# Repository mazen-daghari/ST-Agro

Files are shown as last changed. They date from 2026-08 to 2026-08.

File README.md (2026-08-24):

# ST-Agro: Wireless Data Acquisition and Control System






A low-power, STM32-based wireless data acquisition and control architecture designed for smart agriculture and industrial environmental monitoring. The system consists of a Master/Gateway Node connected to a PC via USB and multiple Sender (Sensor) Nodes deployed in the field. 

System capabilities include integrated SWD firmware deployment, live sensor telemetry (temperature, humidity, multi-gas detection), AI-driven threat assessment (fire/water hazard detection), GPS node mapping, real-time analytics charts, and remote actuator relay matrix control with emergency stop (E-STOP) functionality.

---

## Demonstration & Promotional Videos

* **Promotional Video:** ST-Agro Promotional Video (https://youtu.be/v6s37rHDwMU)
  
---

* **Dashboard Demonstration:** ST-Agro Dashboard Demo (https://youtu.be/QQxuJRQUxHk)

*Click the thumbnails above to view the videos on YouTube.*

---

## System Architecture

System Architecture
---

## Software & Hardware Visual Overview

The system relies on a unified desktop application built in Python using `customtkinter` for modern UI components, `matplotlib` for real-time analytics, `sqlite3` for local persistent storage, and `tkintermapview` for node mapping. The application acts as a dual-purpose software hub:

1. **Direct SWD Hardware Flashing:** Communicates directly with `STM32_Programmer_CLI.exe` to flash compiled binaries (`.elf`) to Master Node (Slot A) and Sender Nodes (Slot B) at base address `0x08000000` over SWD/JTAG interfaces.
2. **LoRa Gateway Supervision & Actuator Control:** Connects to the Master Node over Serial UART to parse incoming sensor telemetry, render live per-node metrics, display active GPS node positions, log background telemetry to SQLite (`node_telemetry.db`), and send remote 4-channel relay control commands or Emergency Stop (`E-STOP`) overrides.
### Application Software Interface

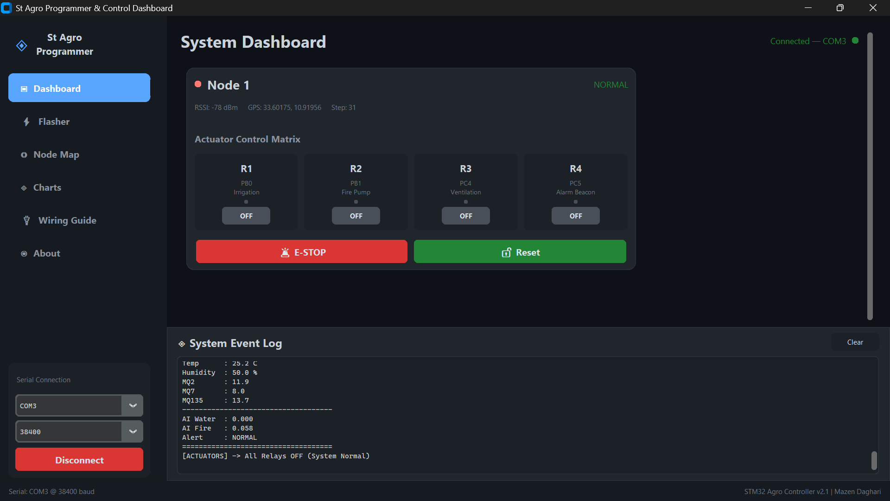
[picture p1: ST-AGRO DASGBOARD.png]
Dashboard View

*Figure 1: ST-Agro Control Dashboard showcasing live telemetry metrics, hazard risk calculations, real-time node statuses, relay controls, and global emergency stop features.*

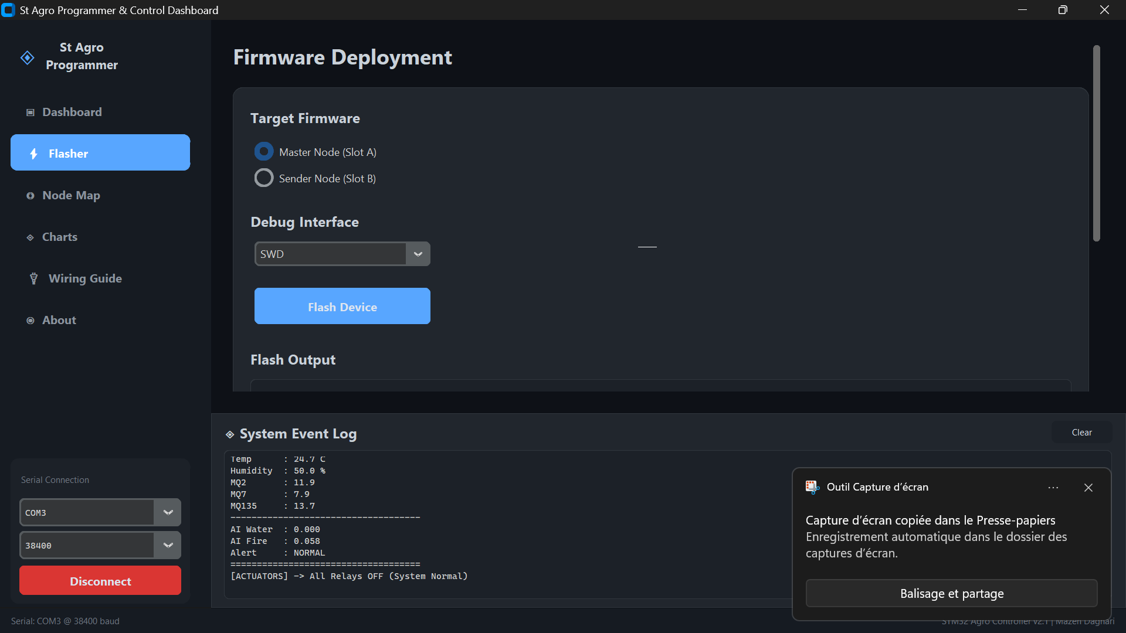
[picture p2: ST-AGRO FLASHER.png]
Flasher View

*Figure 2: SWD Flasher Interface used to flash Master (Slot A) and Sender (Slot B) firmware directly from the desktop application.*

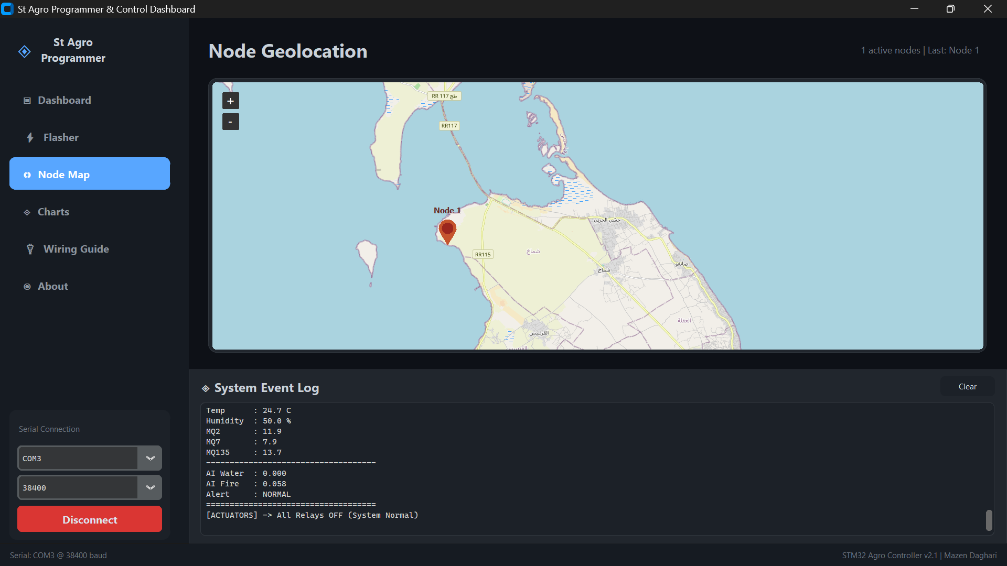
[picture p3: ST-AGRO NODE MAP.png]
Node Map View

*Figure 3: Integrated OpenStreetMap view displaying active field node locations based on live transmitted GPS spatial data.*

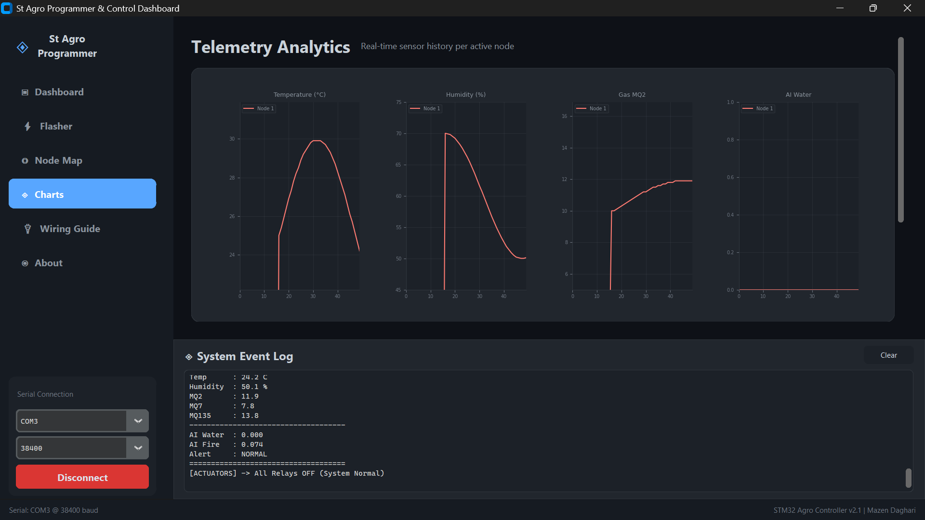
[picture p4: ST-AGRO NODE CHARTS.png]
Analytics Charts View

*Figure 4: Historical and real-time database aggregated analytics visualizing sensor trends and telemetry metrics per node.*

---

### Hardware PCB Layouts
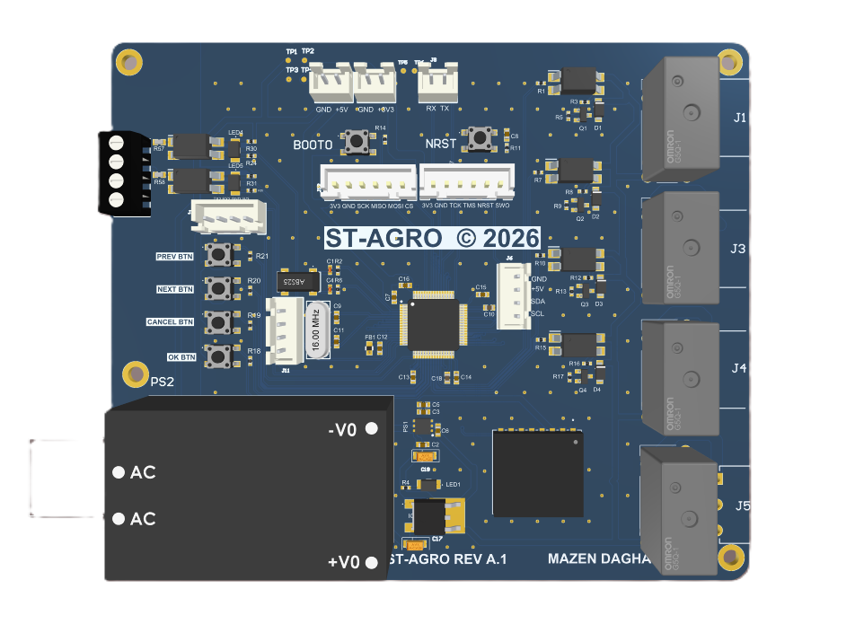
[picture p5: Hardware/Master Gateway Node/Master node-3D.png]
Master Node PCB 3D
.
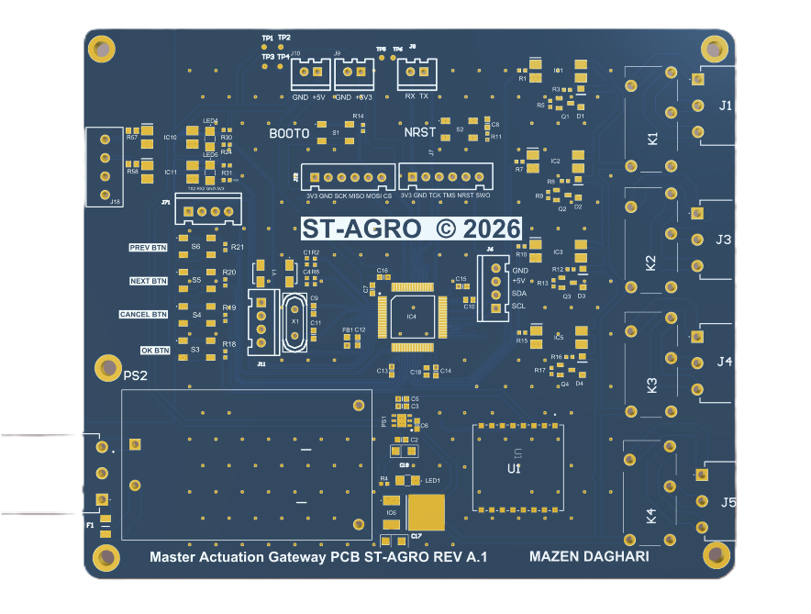
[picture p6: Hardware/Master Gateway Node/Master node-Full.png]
Master Node PCB


*Figure 5: Master/Gateway Node PCB featuring the STM32 microcontroller, USB communication interface, and SWD programming header.*

Sender Node PCB
Sender Node PCB

*Figure 6: Sender (Sensor) Node PCB integrating low-power STM32 architecture, sensor array interfaces, wireless transmitter, and power management circuits.*

---

## Core System Features

* **Integrated SWD Flasher Interface:** Deploy `Master Node (Slot A)` and `Sender Node (Slot B)` firmware binaries directly from the control desktop GUI without requiring external programming tools.
* **Low-Power Deep Sleep Cycle:** Sender nodes perform data collection, transmit packets to the Gateway, and immediately enter a 10-minute ultra-low-power deep sleep state to optimize battery consumption.
* **Multi-Sensor Telemetry Acquisition:**
  * Environmental Data: Temperature and Relative Humidity
  * Gas Array Monitoring: MQ2, MQ7, and MQ135 sensor payload values
* **Threat Intelligence Processing:** Real-time threat calculation providing automated risk scores for Fire Hazard and Water Quality alerts.
* **Actuator Control Matrix:** Remote execution and control of a 4-channel relay array (`R1: Irrigation`, `R2: Fire Pump`, `R3: Ventilation`, `R4: Alarm Buzzer`).
* **Emergency Stop (E-STOP):** Single-click software override that initiates an immediate hardware reset and emergency shutdown state across active nodes.
* **Node Geolocation Tracking:** Integrated OpenStreetMap spatial tracking displaying live GPS locations of active field nodes.
* **Database Aggregated Analytics:** Comprehensive historical and per-node real-time graphical metrics.

---

## Getting Started

### Hardware Requirements

1. Master/Gateway Node PCB (STM32-based controller)
2. Sender Node PCB(s) (STM32-based sensor nodes)
3. ST-LINK V2 / SWD Debugger
4. USB Cable (A-to-Micro or Type-C based on hardware design)
5. Sensor payload array (DHT/SHT series, MQ gas sensors, GPS module)
6. 4-Channel Relay Control Module

---

## Setup and Flashing Instructions

### Step 1: Flash the Master (Gateway) Node

1. Connect the ST-LINK programmer via the SWD header to the Master Node PCB.
2. Launch the **St Agro Programmer & Control Dashboard**.
3. Navigate to the **Flasher** tab on the left panel.
4. Under **Target Firmware**, select **Master Node (Slot A)**.
5. Set the debug interface to **SWD**.
6. Press and hold the hardware **RESET** button on the Master PCB for approximately 3 seconds, then click **Flash Device**.
7. Monitor the **System Event Log** until the process completes with the message `=== FLASH SUCCESSFUL ===`.

### Step 2: Flash the Sender Node(s)

1. Connect the ST-LINK programmer to the target Sender Node PCB.
2. In the **Flasher** tab, select **Sender Node (Slot B)**.
3. Hold the hardware **RESET** button on the Sender PCB for approximately 3 seconds, then click **Flash Device**.
4. Disconnect the debugging interface upon completion.
5. Repeat this sequence for each additional Sender Node within the network topology.

```text
Connect Programmer ──> Select Firmware Slot ──> Hold RESET (3s) ──> Click "Flash Device" ──> Verify Log Output
```

---

## System Operation and Communications

### Gateway Connection

1. Connect the programmed Master Node to the host computer using a USB cable.
2. In the desktop application under **Serial Connection**, click the refresh icon adjacent to the COM port menu.
3. Select the appropriate Master Node port (e.g., `COM3`) and set the baud rate to **38400**.
4. Click **Connect**. The status indicator in the upper right corner will confirm connection status (`Connected - COM3`).

### Node Deployment

1. Apply power to the Sender Node(s).
2. The Sender Node automatically collects sensor metrics and transmits telemetry packets to the Gateway Node.
3. Following each confirmed transmission, the node enters a **10-minute deep sleep cycle** prior to initiating the subsequent measurement cycle.

---

## Application Interface Overview

| Interface Section | Primary Function |
| :--- | :--- |
| **Dashboard** | Monitors active node state, hazard alerts (`FIRE_HAZARD`), live telemetry logs, relay matrix switching, and global **E-STOP** triggers. |
| **Flasher** | In-app firmware deployment interface for Master and Sender binaries via SWD. |
| **Node Map** | Geographical layout visualizing GPS coordinate data transmitted by deployed nodes. |
| **Charts & Global** | Graphical breakdown of historical database records and active per-node metric channels. |

---

## Troubleshooting Guide

* **COM Port Not Detected:** Verify FTDI/UART device driver installation and physical cable connection. Click the refresh control in the Serial Connection settings.
* **Firmware Flashing Failure:** Inspect SWD pin connections (`SWCLK`, `SWDIO`, `GND`, `3V3`). Ensure the physical **RESET** button is held for 3 seconds prior to clicking **Flash Device**.
* **Missing Telemetry Data:** Confirm the Sender node is powered and not currently operating within its 10-minute deep sleep phase. Press the physical RESET button on the Sender node to initiate an immediate transmission.

---
## Core System Features

* **Integrated SWD Flasher Interface:** Direct desktop firmware deployment via `STM32CubeProgrammer` CLI supporting SWD/JTAG modes for Master (`Slot A`) and Sender (`Slot B`) binaries targeting flash address `0x08000000`.
* **Low-Power Deep Sleep Cycle:** Sender nodes collect data, transmit packets to the Gateway, and immediately enter an ultra-low-power 10-minute deep sleep state to conserve battery.
* **Multi-Sensor Telemetry Acquisition:** 
  * Environmental Data: Temperature and Relative Humidity
  * Gas Array & Air Quality Monitoring: MQ2, MQ7, and MQ135 sensor payload values
* **AI-Driven Threat Intelligence:** Automated risk calculation for Fire Hazard (`AI Fire`) and Water Quality (`AI Water`) detection.
* **Actuator Control Matrix:** Remotely toggle a 4-channel relay matrix (`R1: Irrigation`, `R2: Fire Pump`, `R3: Ventilation`, `R4: Alarm Beacon`) on individual field nodes over LoRa.
* **Emergency Stop (E-STOP) Override:** Single-click software override per node that locks controls, turns off active relays, and broadcasts an emergency shutdown command (`NODE:<ID>:EMERGENCY_STOP`).
* **Node Geolocation Tracking:** Embedded OpenStreetMap module (`tkintermapview`) displaying real-time field positions based on live transmitted GPS coordinates.
* **SQLite Telemetry Logging & Analytics:** Automatic local database persistence (`node_telemetry.db`) with real-time per-node streaming charts and aggregated global network averages.
* **Hardware Interfacing Guide:** Built-in pinout reference tables for SWD (PA13/PA14), 20-pin JTAG, and ST-LINK/V2 dongles.
---
## Getting Started

### Hardware Requirements

1. Master/Gateway Node PCB (STM32-based controller)
2. Sender Node PCB(s) (STM32-based sensor nodes)
3. ST-LINK V2 / SWD Debugger
4. USB Cable (A-to-Micro or Type-C based on hardware design)
5. Sensor payload array (DHT/SHT series, MQ gas sensors, GPS module)
6. 4-Channel Relay Control Module

### Software Requirements
* Install and run St Agro Programmer V2.32
---
## Copyright and License

This software and hardware implementation is released under the **MIT License**.

```text
MIT License

Copyright (c) 2026 Mazen Daghari

Permission is hereby granted, free of charge, to any person obtaining a copy
of this software and associated documentation files (the "Software"), to deal
in the Software without restriction, including without limitation the rights
to use, copy, modify, merge, publish, distribute, sublicense, and/or sell
copies of the Software, and to permit persons to whom the Software is
furnished to do so, subject to the following conditions:

The above copyright notice and this permission notice shall be included in all
copies or substantial portions of the Software.

THE SOFTWARE IS PROVIDED "AS IS", WITHOUT WARRANTY OF ANY KIND, EXPRESS OR
IMPLIED, INCLUDING BUT NOT LIMITED TO THE WARRANTIES OF MERCHANTABILITY,
FITNESS FOR A PARTICULAR PURPOSE AND NONINFRINGEMENT. IN NO EVENT SHALL THE
AUTHORS OR COPYRIGHT HOLDERS BE LIABLE FOR ANY CLAIM, DAMAGES OR OTHER
LIABILITY, WHETHER IN AN ACTION OF CONTRACT, TORT OR OTHERWISE, ARISING FROM,
OUT OF OR IN CONNECTION WITH THE SOFTWARE OR THE USE OR OTHER DEALINGS IN THE
SOFTWARE.
```

### Citation Notice

For academic, scientific, or technical research projects utilizing this design, please cite the developer as follows:

* **Author:** Electronic & Communication System Engineer **Mazen Daghari**
* **Project:** ST-Agro Wireless Acquisition System & Control Dashboard
* **Demonstration Reference:** https://youtu.be/QQxuJRQUxHk
 ### Paper & Citation
If you find this work useful in your research, please cite our paper:

> M. Daghari, "ST-Agro: Low-Power Wireless Data Acquisition System," *IEEE...*
> **Preprint / Paper:** [Link]

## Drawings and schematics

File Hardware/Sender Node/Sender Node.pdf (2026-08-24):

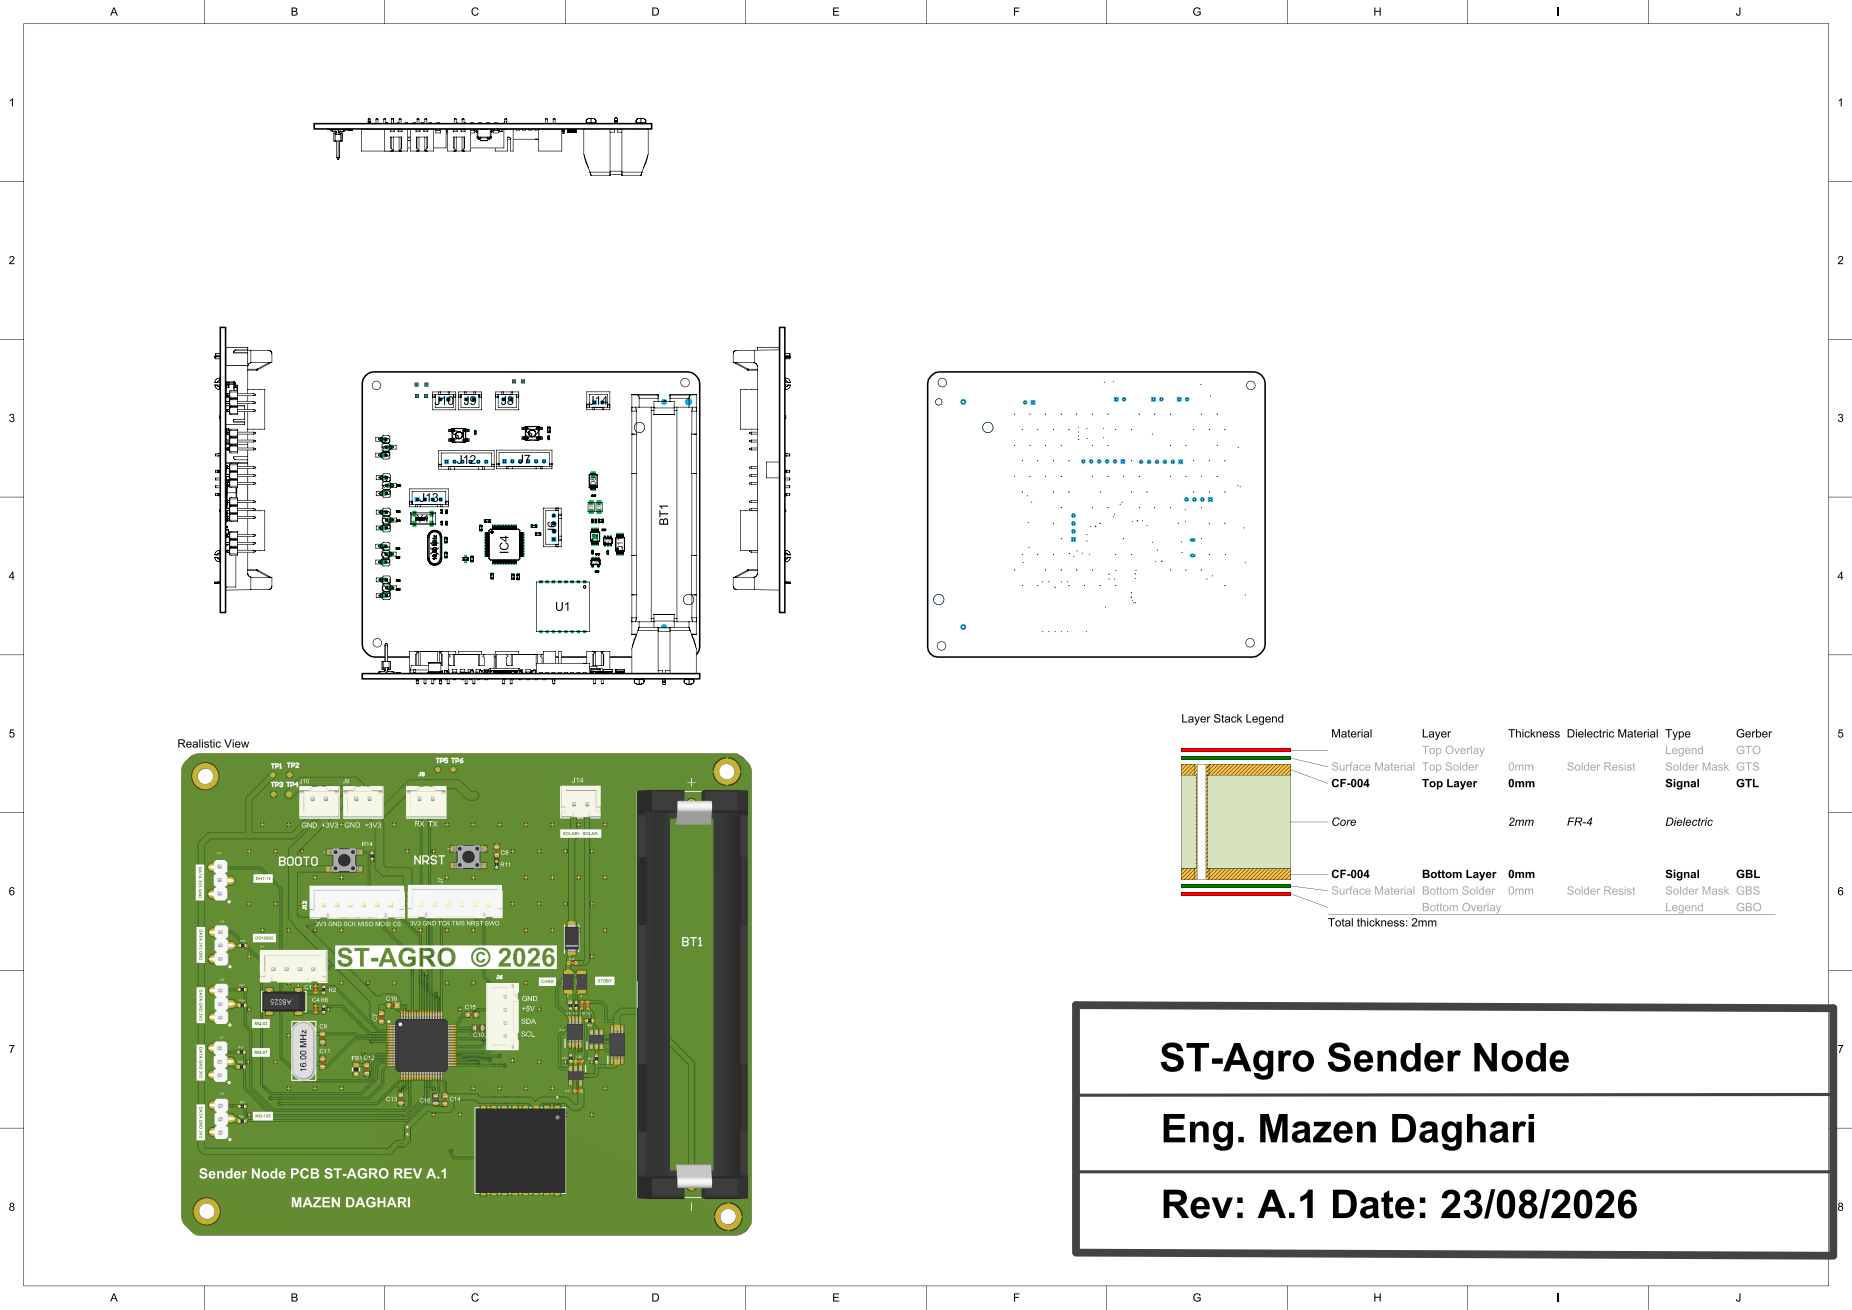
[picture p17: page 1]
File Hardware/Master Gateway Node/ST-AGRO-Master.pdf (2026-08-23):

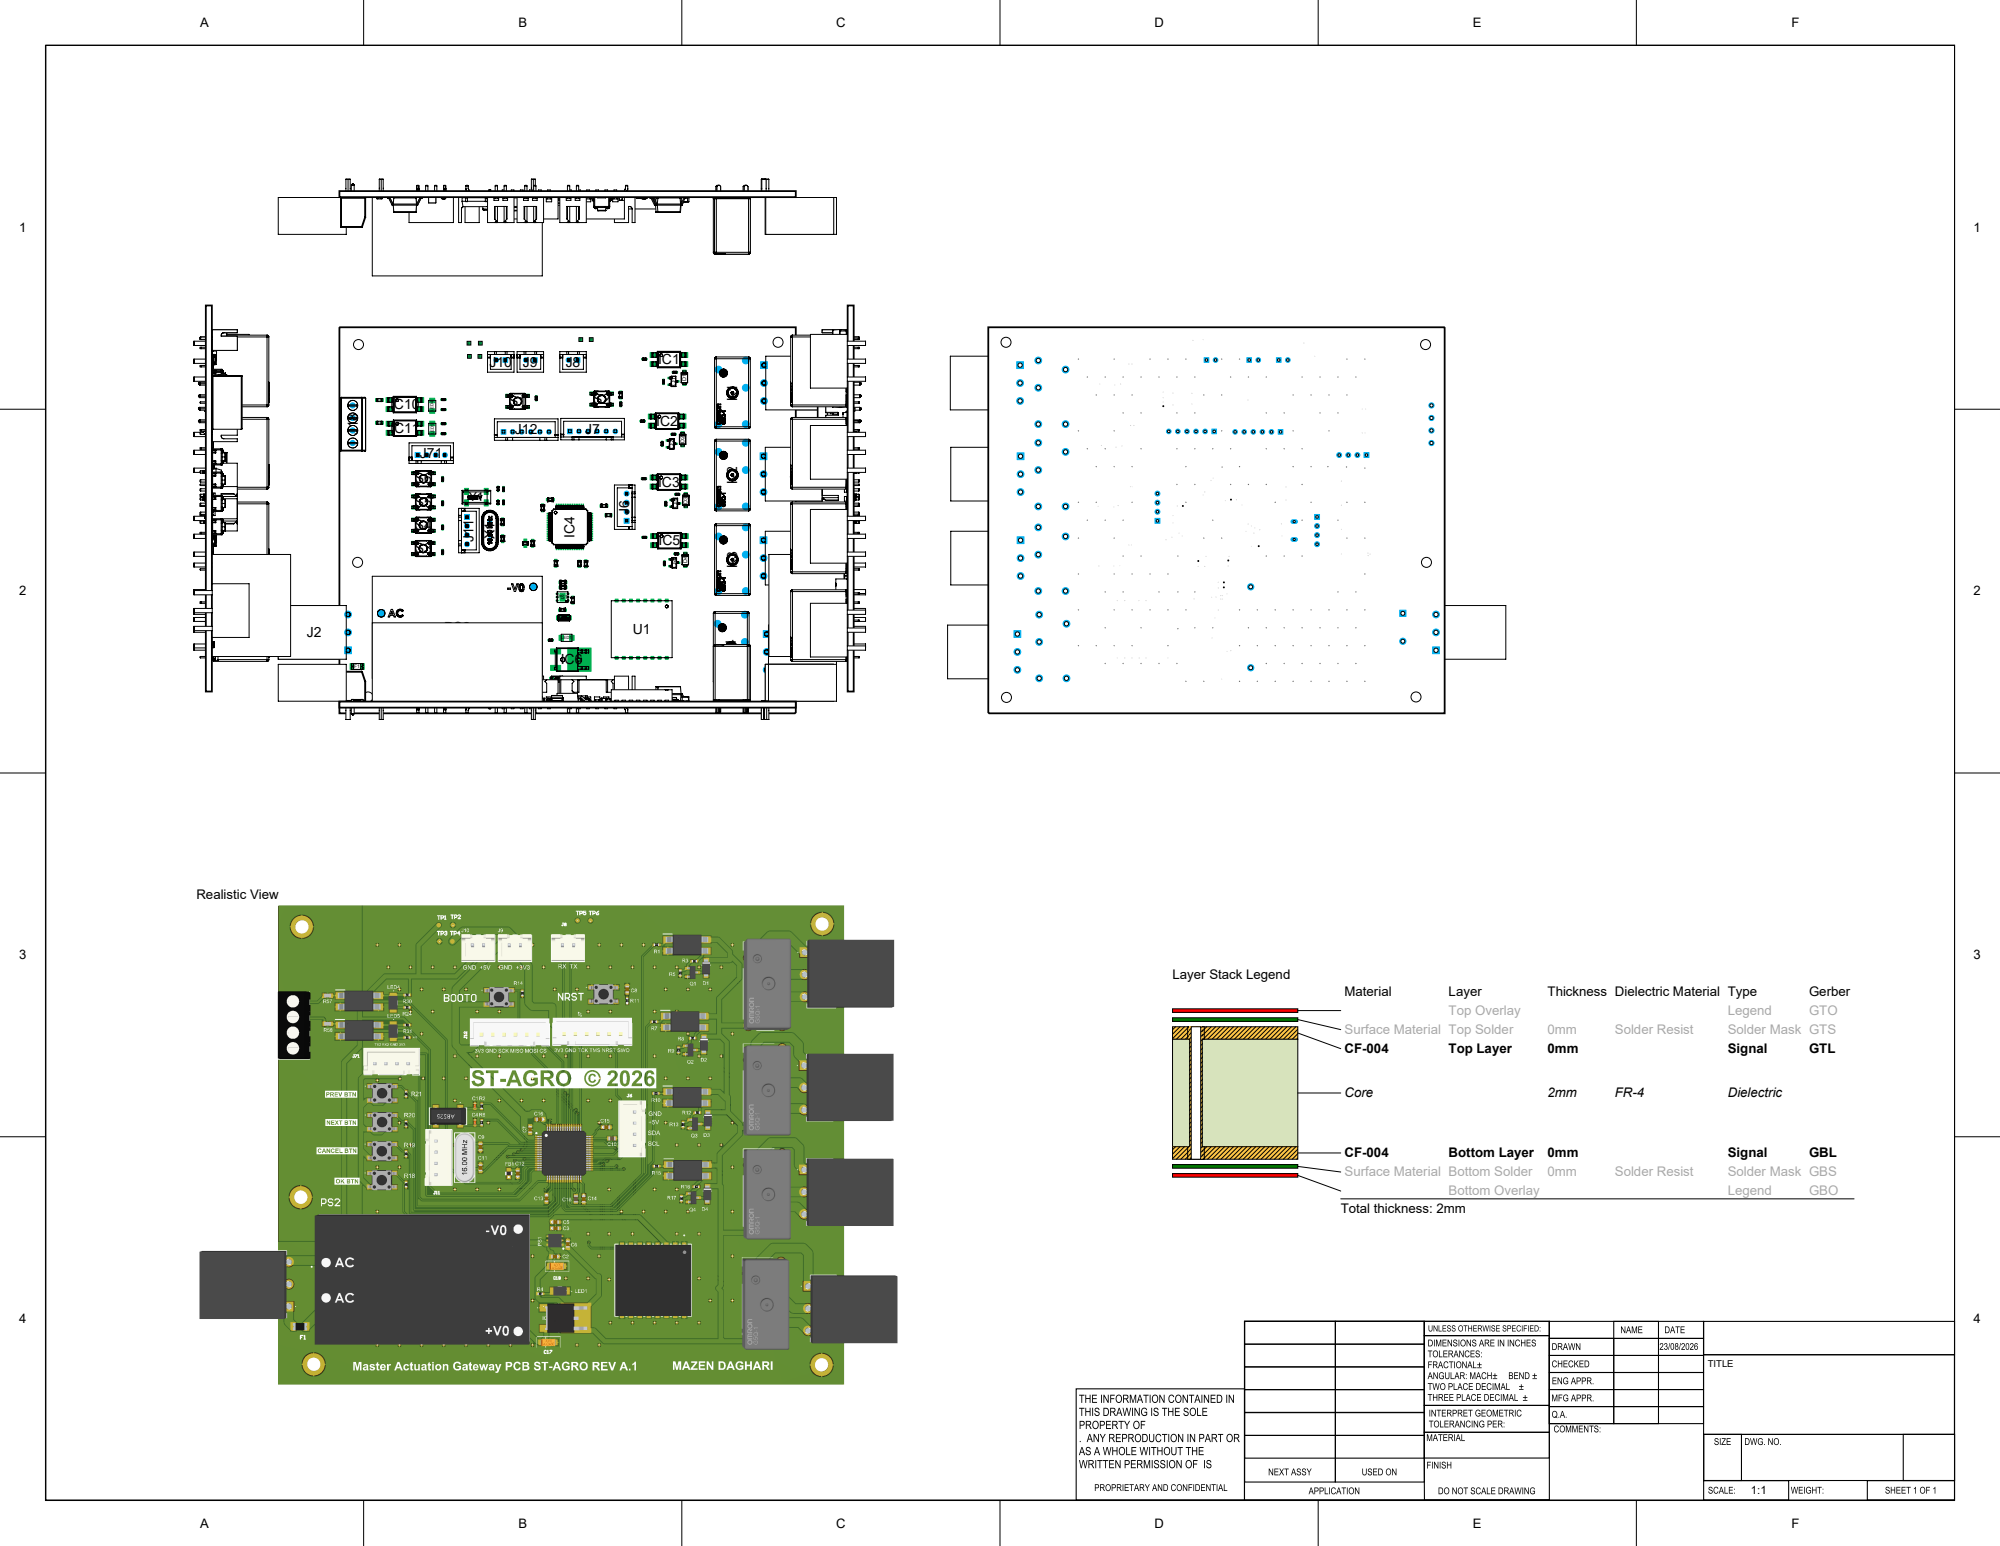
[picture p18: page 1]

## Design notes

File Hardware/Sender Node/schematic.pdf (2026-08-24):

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
Title

Size | Number | Revision
A2
Date: | 8/23/2026 | Sheet of
File: | C:\Users\..\ST-AGRO sender.SchDoc | Drawn By:

R2
0

R6
0

C1

4.3pF

C4

4.3pF

PC15

PC14

PC15

PC14

# Clock configuration

TMS SWO | TCK
NRST | UART⁵_RX UART⁵_TX

RA-02 DIO-0

SWO

NRST

TMS

TCK

3V3 | R14
10K | BOOT⁰

BOOT0

3V3

I2C_SDA

I2C_SCL

R11
10K

NRST

3V3

C8
100nF

# Power configuration

# Boot configuration

# I/O configuration

C9

22pF

C11

22pF

BOOT BTN | Reset BTN

3V3

3V3

3V3

3V3

3V3

C13
100nF

3V3

C14
100nF

C15
100nF

C16
100nF

C12
100nF

AVDD

AVDD

C7
1uF

3V3

Vbat

UART5_RX

UART5_TX

Xtal_in

Xtal_out

VBAT 1
PC13 2
PC14-OSC32_IN 3
PC15-OSC32_OUT 4
PF0-OSC_IN 5
PF1-OSC_OUT 6
NRST 7
PC0 8
PC1 9
PC2 10
PC3 11
VSSA 12
VDDA 13
PA0 14
PA1 15
PA2 16 | PA³ 17 VSS_1 18 VDD_1 19 PA⁴ 20 PA⁵ 21 PA⁶ 22 PA⁷ 23 PC⁴ 24 PC⁵ 25 PB⁰ 26 PB¹ 27 PB² 28 PB¹⁰ 29 PB¹¹ 30 VSS_2 31 VDD_2 32
VDD_3 | 48
VSS_3 | 47
PA13 | 46
PA12 | 45
PA11 | 44
PA10 | 43
PA9 | 42
PA8 | 41
PC9 | 40
PC8 | 39
PC7 | 38
PC6 | 37
PB15 | 36
PB14 | 35
PB13 | 34
PB12 | 33 VDD_4 64 VSS_4 63 PB⁹ ⁶² PB⁸ ⁶¹ BOOT⁰ ⁶⁰ PB⁷ ⁵⁹ PB⁶ ⁵⁸ PB⁵ ⁵⁷ PB⁴ ⁵⁶ PB³ ⁵⁵ PD² ⁵⁴ PC¹² ⁵³ PC¹¹ ⁵² PC¹⁰ ⁵¹ PA¹⁵ ⁵⁰ PA¹⁴ ⁴⁹ | IC4
STM32F303RET6

1

1
2

2

FB1

742792651 ¹ ² XTL_8MHz
X1
CRYSTAL_1 1 | GND_1 | 2
GND_2 | 3 CRYSTAL_2 4

Y1

ABS25-32-768KHZ-T

4

3

2

1

S2 ⁴

3

2

1

S1

I2C_SDA

I2C_SCL

3V3

3V3 | 1 2 | C18
| | GRM188R60J225KE19D

2 1

C10

GRM188R60J225KE19D SPI3_CS SPI3_MOSI | SPI3_MISO SPI3_SCK

SPI3_MOSI
SPI3_CS

SPI3_SCK
SPI3_MISO
3V3 | 3V3 | 3V3

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
UART5_RX | UART5_TX
TP5 | TP6

3.3V 3
MISO 13
MOSI 14
NSS 15
RESET 4
SCK 12

GND 1
GND 2
GND 9
GND 16
DIO0 | 5
DIO1 | 6
DIO2 | 7
DIO3 | 8
DIO4 | 10
DIO5 | 11

U1

RA-02

3V3 RA⁻⁰² RESET

RA-02 NSS

RA-02 SCK

RA-02 MISO

RA-02 MOSI

RA-02 NSS

RA-02 SCK

RA-02 MISO
RA-02 MOSI

RA-02 DIO-0

RA-02 RESET

# Sensors

# SX1278 - Ra-02 Communication Module

# Arm Cortex M4 STM32 f303RE

TEMP | 1
PROG | 2 GND

3

VCC 4
EP 9 CE 8

_CHRG 7
STDBY 6

BAT 5

IC23

TP4056-EMSOP8

D12_1 1
S1_1 2
S1_2 3
G1 4
D12_2 | 8
S2_2 | 7
S2_1 | 6
G2 | 5

Q11

FS8205A

OD 1
CS 2
OC 3
GND | 6
VCC | 5
TD | 4

IC21

DW01A-G | P N
BT1
1043
R42
15K
R41

1.5K ¹ ² LED7 1 2 LED6

C33
100nF

R43
4.7K

VIN 1
GND 2
SHUTDOWN 3
NC/ADJ | 4
VOUT | 5

IC20

AP2127K-3.0TRG1

R44
1.2K

C34
100nF

R45
100
C35
10uF 1
2
J14

+V SolarP

-V SolarP

+OUT

-OUT

C36
1uF

C37
10uF

3V3

2 1

D8

B140-E3_61T

R47
10K R48 18K

GND

MQ-02
R46
4.7K

3V3

DS18B20-Data PIN

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
J203V3 GND

R49
10K R50 18K

GND

MQ-07

1

2

3

J213V3 GND

R51
10K R52 18K

GND

MQ-135

1

2

3

J22 1 | 3V3 GND

2

3

J18
GND

3V3

DHT-11

3V3

3V3

DHT-11
DS18B20-Data PIN | MQ⁻⁰² | MQ⁻⁰⁷ MQ⁻¹³⁵
UART2_TX | UART²_RX

UART2_RX

UART2_TX 1
2
3
4
J13 | 3V3

* Sensors use **analog pins only**; digital pins must not be connected. The **DS18B20** sensor is used to ensure high-precision temperature measurement in harsh environments.

## SOLAR ENERGY HARVESTING & BATTERY MANAGEMENT SUBSYSTEM (SENDER NODE)

## 1. SOLAR PANEL INPUT SPECIFICATIONS:

- Rated Output: 5.5V / 290mA Photovoltaic (PV) Cell.
- Input Blocking Diode: MBR0540 (Schottky) to prevent reverse battery discharge.
- Transient Protection: SMAJ6.0A TVS diode placed across VIN to GND.

## 2. CHARGER IC PROGRAMMING (MCP73831 / EQUIVALENT):

- R_PROG Value: 3.9kΩ to 4.7kΩ (1%, 0402).

## - Fast-Charge Current Setting: ~220mA - 256mA (Matched to panel capability

to prevent solar voltage collapse and continuous UVLO oscillation).

## 3. DECOUPLING & FILTERING CAPACITORS:

- C_IN (VIN to GND): 4.7µF X5R/X7R Ceramic (0805) placed at IC input.

## - C_OUT (VBAT to GND): 10µF X5R/X7R Ceramic (0805) placed at battery

terminal.

## 4. LAYOUT & THERMAL GUIDELINES:

- Keep PROG resistor trace short and isolated from noisy RF/LoRa traces.
- Provide adequate copper pour under VSS (GND) pin for thermal dissipation. ----------------------------------------------------------------------------------------------------

* Press and hold the **RESET button for 3 seconds** while the firmware is flashing.

## Author: Mazen Daghari

## ST-Agro Sender Node

A.1

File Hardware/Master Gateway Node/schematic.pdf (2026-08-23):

# Clock configuration Power configuration

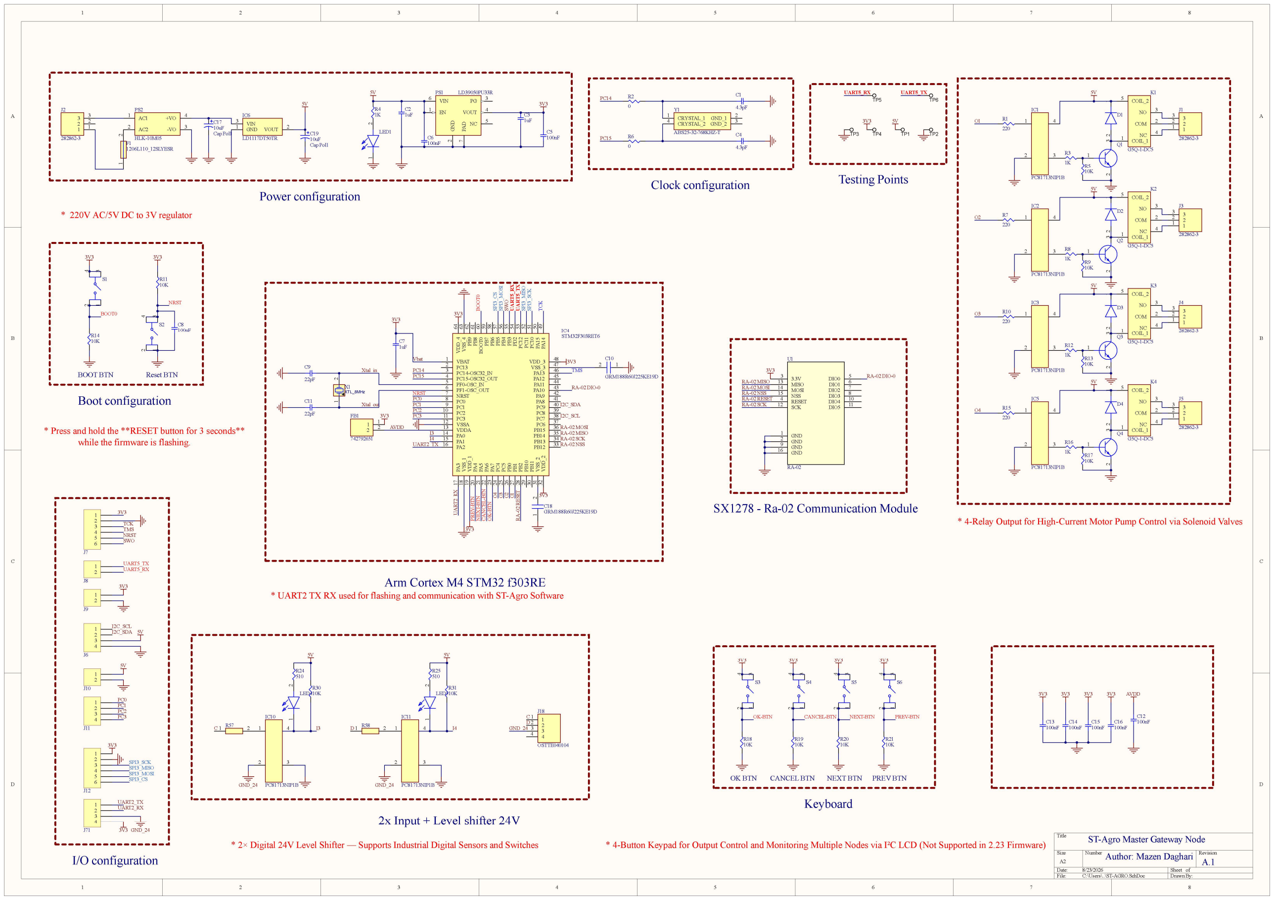
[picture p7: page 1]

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
Title

Size | Number | Revision
A2
Date: | 8/23/2026 | Sheet of
File: | C:\Users\..\ST-AGRO.SchDoc | Drawn By:

C2
1uF

C6
100nF

R4
1K | C3
| 1uF

C5
100nF

R2
0

R6
0

C1

4.3pF

C4

4.3pF

PC15

PC14

PC15

PC14

TMS SWO | TCK
NRST | UART⁵_RX UART⁵_TX

RA-02 DIO-0

SWO

NRST

TMS

TCK

3V3

R14

10K | BOOT⁰

BOOT0

3V3

3V3

5V

5V

I2C_SDA 5V

I2C_SCL

R11
10K

NRST

3V3

C8
100nF

# Boot configuration

# I/O configuration

C9

22pF

C11

22pF

BOOT BTN | Reset BTN

3V3

3V3

3V3

3V3

3V3

C13
100nF

3V3

C14
100nF

C15
100nF

C16
100nF

C12
100nF

AVDD

AVDD

C7
1uF

3V3

Vbat

UART5_RX

UART5_TX

Xtal_in

Xtal_out

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
GND_24

R30
10K

I3

R24
510

5V

GND_24

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
282862-3

1

1

2

2

3

3

J4

282862-3

1

1

2

2

3

3

J3

282862-3

1

1

2

2

3

3

J1

282862-3

1 | 2 3 | Q4
1 | 2 3 | Q3
1 | 2 3 | Q2
1 | 2 3 | Q1

1 2

# D4 ¹ ²

# D3 ¹ ²

# D2 ¹ ²

D1

COIL_1 1

COM | 2
NO | 3
NC | 4

COIL_2 5

K4

G5Q-1-DC5

COIL_1 1

COM | 2
NO | 3
NC | 4

COIL_2 5

K3

G5Q-1-DC5

COIL_1 1

COM | 2
NO | 3
NC | 4

COIL_2 5

K2

G5Q-1-DC5

COIL_1 1

COM | 2
NO | 3
NC | 4

COIL_2 5

K1

G5Q-1-DC5

1

2

4

3

IC11

PC81713NIP1B

1

2

4

3

IC10

PC81713NIP1B

1

2

4

3

IC5

PC81713NIP1B

1

2

4

3

IC3

PC81713NIP1B

1

2

4

3

IC2

PC81713NIP1B

1

2

4

3

IC1

PC81713NIP1B

VBAT 1
PC13 2
PC14-OSC32_IN 3
PC15-OSC32_OUT 4
PF0-OSC_IN 5
PF1-OSC_OUT 6
NRST 7
PC0 8
PC1 9
PC2 10
PC3 11
VSSA 12
VDDA 13
PA0 14
PA1 15
PA2 16 | PA³ 17 VSS_1 18 VDD_1 19 PA⁴ 20 PA⁵ 21 PA⁶ 22 PA⁷ 23 PC⁴ 24 PC⁵ 25 PB⁰ 26 PB¹ 27 PB² 28 PB¹⁰ 29 PB¹¹ 30 VSS_2 31 VDD_2 32
VDD_3 | 48
VSS_3 | 47
PA13 | 46
PA12 | 45
PA11 | 44
PA10 | 43
PA9 | 42
PA8 | 41
PC9 | 40
PC8 | 39
PC7 | 38
PC6 | 37
PB15 | 36
PB14 | 35
PB13 | 34
PB12 | 33 VDD_4 64 VSS_4 63 PB⁹ ⁶² PB⁸ ⁶¹ BOOT⁰ ⁶⁰ PB⁷ ⁵⁹ PB⁶ ⁵⁸ PB⁵ ⁵⁷ PB⁴ ⁵⁶ PB³ ⁵⁵ PD² ⁵⁴ PC¹² ⁵³ PC¹¹ ⁵² PC¹⁰ ⁵¹ PA¹⁵ ⁵⁰ PA¹⁴ ⁴⁹ | IC4
STM32F303RET6

1

1
2

2

FB1

742792651 ¹ ² XTL_8MHz
X1
CRYSTAL_1 1 | GND_1 | 2
GND_2 | 3 CRYSTAL_2 4

Y1

ABS25-32-768KHZ-T

EN 1 | GND

2

PG 3 PAD

7

VIN 6

NC | 5
VOUT | 4
PS1 | LD39050PU33R 1 2 | LED4 | 1 2 | LED5 ¹ ² LED1 4

3

2

1

S2 ⁴

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
UART2_TX

I2C_SDA

I2C_SCL

3V3

3V3

1 | 2 R58 1 | 2 R57 | 1 2 | C18

GRM188R60J225KE19D

2 1

C10

GRM188R60J225KE19D

C | D | SPI3_CS SPI3_MOSI | SPI3_MISO SPI3_SCK

SPI3_MOSI
SPI3_CS

SPI3_SCK
SPI3_MISO

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
OSTTE040104

3V3 | 3V3 | 3V3

AC1 1

AC2 2

-VO | 3
+VO | 4

PS2

HLK-10M05

TP1

5V

TP2 1 2 F1

1206L110_12SLYESR

1

1

2

2

3

3

J2

282862-3

GND 1 | VOUT | 2

VIN 3

IC6

LD1117DT50TR

10uF

C17

Cap Pol1
10uF

C19

Cap Pol1

C
D
GND_24

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
UART5_RX | UART5_TX
TP5 | TP6

3.3V 3
MISO 13
MOSI 14
NSS 15
RESET 4
SCK 12

GND 1
GND 2
GND 9
GND 16
DIO0 | 5
DIO1 | 6
DIO2 | 7
DIO3 | 8
DIO4 | 10
DIO5 | 11

U1

RA-02

3V3 RA⁻⁰² RESET

RA-02 NSS

RA-02 SCK

RA-02 MISO

RA-02 MOSI

RA-02 NSS

RA-02 SCK

RA-02 MISO
RA-02 MOSI

RA-02 DIO-0

RA-02 RESET

R18
10K

OK-BTN

3V3

# OK BTN ⁴

3

2

1

S3

R19
10K

CANCEL-BTN

3V3

# CANCEL BTN ⁴

3

2

1

S4

R20
10K

NEXT-BTN

3V3

# NEXT BTN ⁴

3

2

1

S5

R21
10K

PREV-BTN

3V3

# PREV BTN ⁴

3

2

1

S6

# 2x Input + Level shifter 24V

# Keyboard

# SX1278 - Ra-02 Communication Module

# Arm Cortex M4 STM32 f303RE PREV⁻BTN NEXT⁻BTN CANCEL⁻BTN OK⁻BTN O⁴ O³ O² O¹

UART2_TX
UART2_RX 1
2
3
4
J71 | 3V3 GND_24 | UART²_RX

# Testing Points

# * 2× Digital 24V Level Shifter — Supports Industrial Digital Sensors and Switches

# * Press and hold the **RESET button for 3 seconds**

while the firmware is flashing.

# * 220V AC/5V DC to 3V regulator

* 4-Button Keypad for Output Control and Monitoring Multiple Nodes via I²C LCD (Not Supported in 2.23 Firmware)

# * UART2 TX RX used for flashing and communication with ST-Agro Software

# * 4-Relay Output for High-Current Motor Pump Control via Solenoid Valves

# ST-Agro Master Gateway Node

# A.1 Author: Mazen Daghari

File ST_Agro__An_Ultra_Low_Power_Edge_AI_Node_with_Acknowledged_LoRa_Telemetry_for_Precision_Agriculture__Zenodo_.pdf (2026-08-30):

## ST-Agro: An Ultra Low Power Edge AI Node with Acknowledged LoRa Telemetry for Precision Agriculture

Mazen Daghari∗

August 2026

Preprint Repository Release – Hosted on Zenodo (doi:10.5281/zenodo.22063158) (https://doi.org/10.5281/zenodo.22063158) Available under Creative Commons Attribution 4.0 International (CC BY 4.0)

Abstract

This paper presents ST-Agro, an autonomous wireless sensing edge node engineered for precision agriculture that seamlessly integrates embedded machine learning with long-range radio telemetry. Constructed around the STM32F303RE microcontroller and the RA02 SX1278 LoRa module operating within the 433 MHz ISM frequency band, the platform executes a multilayer perceptron classifier compiled via STM32Cube.AI. On-node inference detects agronomic stress states, specifically hydric deficit and combustion risk, thereby eliminating external cloud processing dependency for latency-critical decisions. Model validation on a 1,440-instance hybrid field and micro-chamber dataset using 5-fold cross-validation demonstrates near-optimal classification fidelity, reaching an area under the ROC curve (AUC) of 1.00 for both targets, with 100% sensitivity for fire hazard detection and 99.3% overall accuracy for irrigation needs. A lightweight acknowledged protocol featuring Modbus CRC16 error detection and exponential backoff retransmission operates over a compact binary frame format. To ensure extended operation, the system utilizes the STM32 STOP mode, periodically resuming execution via an RTC alarm driven by the internal low-speed oscillator, alongside a 30-second localized preheating phase for power-gated gas sensors. Experimental evaluations demonstrate an average operational current consumption of 38 µA at 3.7 V, corresponding to an operational longevity exceeding 18 months on a standard 3400 mAh 18650 lithium-ion cell. Furthermore, a 0.15W photovoltaic transducer provides sufficient energy generation for perpetual off-grid execution. Empirical field trials validate robust packet delivery at signal levels between −77 dBm and −89 dBm over a 125 kHz LoRa bandwidth using spreading factor 7.

Keywords: Edge AI, LoRa, STM32, Precision Agriculture, Low Power Design, STM32Cube.AI, SX1278, PCB Design, Internet of Things, TinyML.

## 1 Introduction

The convergence of embedded artificial intelligence and low-power wide-area networks (LPWAN) is revolutionizing modern precision agriculture. Traditional cloud-centric telemetry systems introduce non-deterministic latency, exhibit vulnerability to cellular outages in remote rural regions, and incur recurring bandwidth overhead. In contrast, edge intelligence shifts computational inference directly to the sensing node, facilitating instantaneous actuation while transmitting strictly condensed diagnostic metrics [5, 16].
This work introduces ST-Agro, a comprehensive edge-to-gateway telemetry framework designed for continuous agronomic monitoring. The node acquires five environmental variables,

∗Mazen Daghari is an Independent Researcher in Electronic and Communication Systems (e-mail: dagmazen@gmail.com).

1

Zenodo Open-Access Preprint | ST-Agro: Edge AI & Telemetry Node

comprising ambient temperature, relative humidity, and three distinct gaseous concentrations (LPG, CO, and volatile air quality metrics), which are subsequently fed into a neural network quantized for the ARM Cortex-M4F core. The resulting inference outputs (hydric stress, fire hazard, or nominal state) are encapsulated within a 32-byte binary payload and transmitted via LoRa to a primary receiver. An acknowledged uplink protocol featuring CRC16 error detection guarantees data integrity across unlicensed spectrum.
The primary academic and engineering contributions of this paper are:
- A fully open-source firmware stack engineered for STM32F3 and SX1278 hardware that orchestrates AI inference, acknowledged LoRa telemetry, and deterministic low-power sleep scheduling with preheating compensation;
- Custom 2-layer PCB hardware designs for both solar-harvesting Edge Transmitter nodes and high-reliability Master Actuation Gateways;
- Empirical validation of a lightweight multilayer perceptron evaluated on a 1,440-sample dataset via 5-fold cross-validation, achieving near-perfect diagnostic accuracy across dual agricultural targets while maintaining minimal execution complexity;
- A validated empirical power model confirming that a 3.7 V, 3400 mAh 18650 cell sustains a 10-minute reporting interval for over 1.5 years;
- A lightweight acknowledged protocol (7-byte ACK frame) featuring configurable retry logic optimized to execute within a bounded 300 ms reception window.

## 2 Related Work

Recent literature concerning agricultural IoT systems focuses primarily on two key domains:
(1) ultra-low-power wide-area telemetry using LoRa protocols, and (2) TinyML deployment for localized crop health diagnostics [21].
Borja Jimenez et al. [1] and Mekki et al. [17] comprehensively evaluated LPWAN technologies for smart farming, emphasizing LoRa’s superior link budget across densely vegetated environments compared to NB-IoT and Sigfox. Nevertheless, conventional deployments predominantly rely on Class A LoRaWAN, which lacks guaranteed downlink acknowledgment within a deterministic timeframe. Our work replaces standard LoRaWAN MAC layers with a bespoke primary-secondary protocol, trading massive network scalability for bounded latency and reduced packet overhead. Regarding edge AI integration, STM32Cube.AI was evaluated for phytopathological detection by Ferreira et al. [2], achieving execution latency under 10 ms on STM32L4 architectures. Similarly, foundational frameworks like TensorFlow Lite for Microcontrollers have enabled widespread adoption of TinyML paradigms [4, 16]. While previous approaches often processed high-dimensional image data, we prove that a compact multilayer perceptron operating on scalar environmental metrics provides sufficient sensitivity for real-time anomaly detection within greenhouse and open-field environments.
To the best of our knowledge, no existing literature demonstrates the unified integration of custom 2-layer PCB layout, STM32Cube.AI neural inference, acknowledged LoRa telemetry, and sleep current draw below 40 µA within a single open-source framework tailored for dual-target agricultural monitoring.

## 3 System Architecture

Fig. 1 illustrates the overall ST-Agro system topology. The sensing node (transmitter) incorporates three principal modules: (i) the analog sensor acquisition front end, (ii) the edge AI inference engine, and (iii) the acknowledged LoRa communication subsystem. The primary receiver node

DOI: 10.5281/zenodo.22063158 (https://doi.org/10.5281/zenodo.22063158) | Page 2

acts as an actuation gateway, decoding incoming telemetry frames, displaying geo-coordinates during emergency states, actuating local hardware mitigation circuits, and returning confirmation acknowledgments.

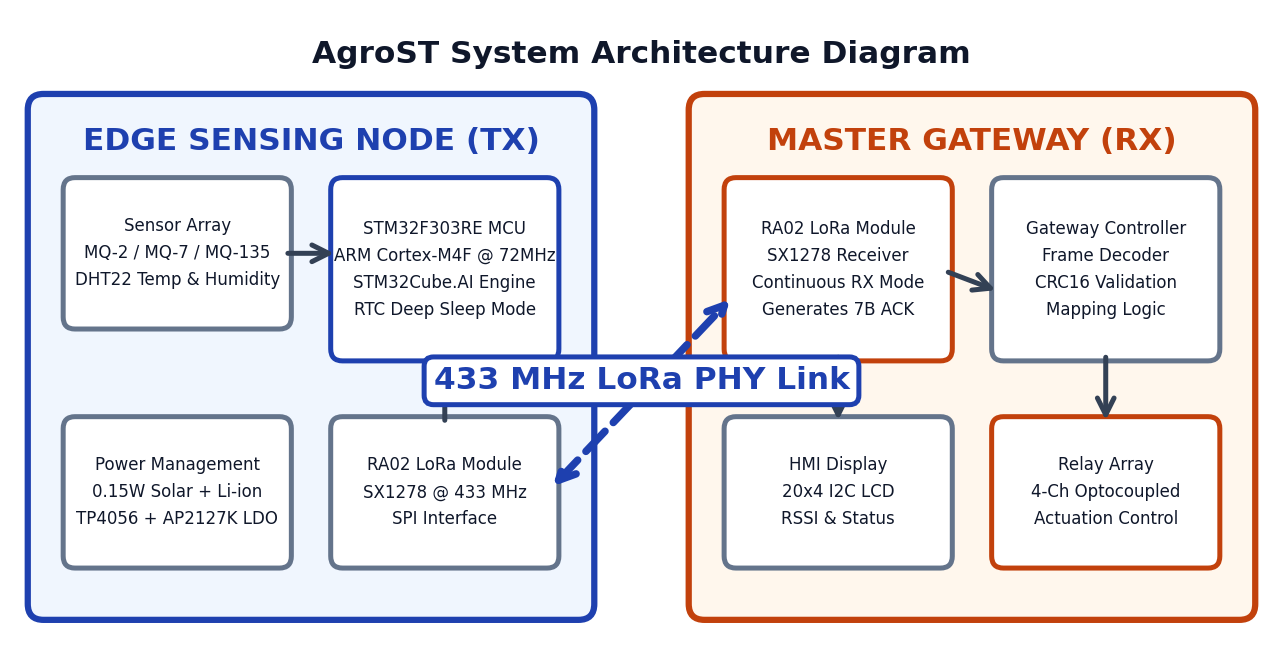
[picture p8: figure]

Figure 1: ST-Agro architectural block diagram depicting the sensing edge node (left) and primary receiver master gateway (right).

### 3.1 Hardware Interconnects

The primary sensing edge node is built around an STM32F303RE microcontroller (ARM Cortex-M4F, 72 MHz, 512 kB Flash, 80 kB SRAM). The LoRa wireless subsystem utilizes an AI-Thinker RA02 module based on the Semtech SX1278 transceiver. SPI2 (PB13–PB15) handles high-speed data transfer, while software chip select (PB12) ensures bus stability. Pin interconnects are outlined in Table 1.

Table 1: RA02 Transceiver to STM32F303RE Interface
RA02 Pin | STM32 Pin | Function
VCC | 3.3 V | Main power supply
GND | GND | Common ground
NSS | PB12 (GPIO Out) | Software chip select
SCK | PB13 (SPI2 SCK) | Serial clock
MISO | PB14 (SPI2 MISO) Master in slave out
MOSI | PB15 (SPI2 MOSI) Master out slave in
RST | PA8 (GPIO Out) | Hardware reset
DIO0 | PA9 (GPIO In) | Interrupt line (RxDone / TxDone)

The analog front end employs the internal 12-bit ADC (ADC1) across five multiplexed channels: ambient temperature (CH1), relative humidity (CH2), MQ2 combustible gas (CH4), MQ7 carbon monoxide (CH8), and MQ135 air quality (CH9). Conversions are executed sequentially using a 19.5 cycles sampling interval.

### 3.2 Edge AI Model, Dataset Verification & Quantization Benchmarking

A fully connected multilayer perceptron comprising two hidden layers (16 and 8 nodes with ReLU activations) is trained offline in Python and compiled for deployment via STM32Cube.AI [11]. The network receives five standardized environmental variables and generates two bounded

outputs:

ywater ∈ [0, 1], | irrigation requirement index | (1)
yfire ∈ [0, 1], | combustion hazard probability | (2)

Feature scaling adheres to standard z-score normalization:

x

′
i =

xi − µi
σi
, | i = 1 . . . 5, | (3)

where vector parameters µi and σi are embedded directly into internal flash storage. Forward pass execution is invoked synchronously through stai network run(net, STAI MODE SYNC). The overall architecture requires 232 Multiply-Accumulate operations (MACs) per forward inference pass.
To evaluate resource trade-offs on the ARM Cortex-M4F core (72 MHz), the model was compiled across three numerical representations using X-CUBE-AI. Table 2 summarizes flash memory footprint, RAM utilization, execution latency, and classification accuracy across formats [8].

Table 2: STM32Cube.AI Model Quantization & Memory Benchmarking
Precision | Flash (kB) SRAM (kB) Latency (ms) Accuracy (%)
FP32 | 4.12 | 0.48 | 1.80 | 99.65
FP16 | 2.24 | 0.32 | 1.25 | 99.65
INT8 | 1.18 | 0.21 | 0.62 | 99.30

Although 8-bit integer quantization (INT8) reduces memory consumption by 71.3% and lowers inference latency to 0.62 ms, the default FP32 model was deployed due to the abundance of available flash (512 kB) on the STM32F303RE, preserving maximum dynamic precision for risk probability calculations.
Model validation was performed on a custom 1,440-instance hybrid agricultural dataset (1,000 field entries and 440 micro-chamber stress simulations) using a 5-fold cross-validation scheme (80/20 train/test split per fold). While near-optimal diagnostic metrics (1.00 AUC, 100% sensitivity) were obtained under these controlled micro-chamber conditions, broader multi-season field deployments across varied macro-climates are required to fully evaluate edge generalization robustness against environmental drift [15].

## 4 Hardware Design and 2-Layer PCB Architecture

To transition the ST-Agro framework from breadboard prototypes to field-deployable units, custom 2-layer Printed Circuit Boards (PCBs) were designed in Altium Designer for both the Transmitter Sensing Node and the Master Actuation Gateway (shown in Fig. 4). Note that the underlying physical PCB fabrication silkscreen bears the hardware design iteration identifier ST-Agro, which directly corresponds to the ST-Agro system architecture described herein.

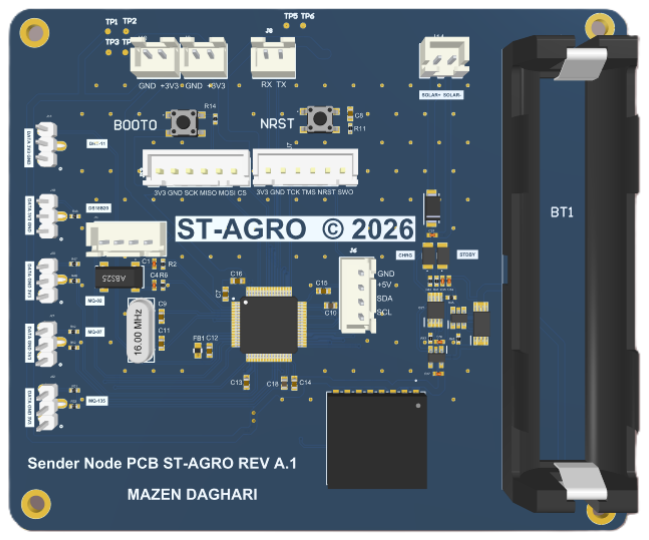
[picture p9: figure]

Figure 2: (a) Transmitter Sensing Edge Node 2-layer PCB layout.

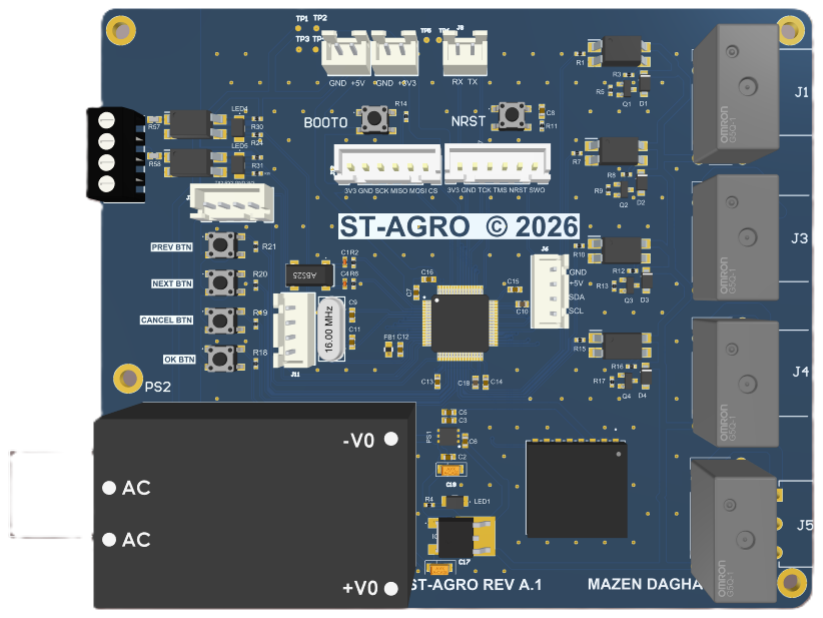
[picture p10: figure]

Figure 3: (b) Master Actuation Gateway PCB layout with optocoupled relays.

Figure 4: Custom 2-layer PCB hardware designs for the ST-Agro system: (a) Solar-harvesting edge node, and (b) High-reliability actuation gateway node.

### 4.1 Transmitter Sensing Edge Node PCB & Preheating Strategy

As illustrated in Fig. 2, the Transmitter PCB integrates power management, environmental sensing, computational processing, and long-range RF transmission onto a compact 2-layer board (65 × 45 mm).

- Energy Harvesting Management: An onboard TP4056 charging IC combined with a DW01A battery protection circuit manages charge cycles from a 5 V, 0.15W mini polycrystalline solar panel to a single-cell 18650 Li-ion battery (3.7 V, 3400 mAh). An ultra-low quiescent LDO (AP2127K, Iq = 1.6 µA) steps down voltage to a clean 3.3 V logic rail.
- Sensor Power-Gating & Warm-Up Compensation: Metal-oxide gas sensors (MQ series) require thermal baseline stabilization. To prevent static power drain during STOP sleep, N-channel MOSFET switches fully power-gate the sensor heater elements. Upon RTC timer wakeup, the firmware enforces a localized 30 s heater preheating phase (Iheater ≈ 12 mA) to purge chemical drift before ADC sampling, ensuring high measurement precision without compromising long-term battery autonomy.
- RF Subsystem & Ground Plane Routing: The RA02 LoRa module connects via a impedance-matched coplanar waveguide with ground (CPWG) trace terminating at an SMA connector. Utilizing a cost-effective 2-layer stackup, the bottom layer functions primarily as a continuous ground pour to provide shielding, minimize loop inductance, and stabilize RF transmission, while signal and power routing are carefully isolated on the top layer.

### 4.2 Master Actuation Gateway PCB

Fig. 3 showcases the Master Gateway PCB, which serves as a high-reliability field controller designed to handle continuous mains or high-capacity power while executing real-time control routines.

- Four-Channel Relay Output Module: Four optocoupled high-current relays (SRD-05VDC-SL-C) are integrated directly onto the PCB, providing 250 V AC / 10 A isolation. Relay 1 actuates an acoustic/optical alarm tower; Relay 2 opens a high-pressure solenoid valve for automated fire suppression; Relay 3 manages the agricultural irrigation pump; and Relay 4 acts as an auxiliary expansion trigger. Optocoupler isolation (PC817) prevents inductive back-EMF spikes from coupling into the STM32 processing core.
- Human-Machine Interface (HMI): A 20×4 character LCD driven via an I2C expansion module (PCF8574) is embedded on the front panel. Upon receiving an emergency frame (yfire > 0.50), the gateway decodes the node identifier, maps it to pre-programmed spatial coordinates, and flashes the location along with RSSI metrics on the LCD screen.
- LoRa Telemetry Subsystem: An RA02 module operates continuously in RX mode (Irx ≈ 12 mA) with an external 433 MHz high-gain dipole antenna connected via IPEX-to-SMA pigtail.

Table 3: Master Gateway Hardware Actuation Logic

Trigger State | Actuated Relay | System Response Ac-
tion
yfire > 0.50 | Relay 1 & Relay 2 | Trigger | siren/strobe
alarm | and | open | au-
tomated deluge valve;
display coordinates on
LCD.
ywater > 0.70 | Relay 3 | Engage agricultural ir-
rigation pump for calibrated duration.
yfire ≤ 0.50 | Relay 4 | Maintain auxiliary moni-
toring systems.

## 5 Communication Technology Spectrum and Protocol Comparison

Selecting an appropriate communication technology for precision agriculture involves balancing propagation range, power budget, payload bandwidth, and network infrastructure overhead.

### 5.1 Disambiguation: LoRa Modulation vs. LoRaWAN Protocol

A fundamental architectural distinction exists between LoRa and LoRaWAN :

- LoRa (Long Range): Refers strictly to the proprietary physical layer (PHY) modulation technology developed by Semtech. It utilizes Chirp Spread Spectrum (CSS) modulation to encode data onto linear frequency-swept pulses, achieving high receiver sensitivity (down to −137 dBm) and resilience against multipath fading and Doppler shifts [10, 20].
- LoRaWAN: Refers to an open, standardized Media Access Control (MAC) layer protocol managed by the LoRa Alliance. It governs regional frequency channel plans, adaptive data rate (ADR) algorithms, AES-128 network security join procedures, and Class A/B/C device scheduling across centralized star topologies connected to regional cloud Network Servers.

In ST-Agro, we deliberately bypass the heavy MAC layer of LoRaWAN. Instead, ST-Agro utilizes raw LoRa physical layer modulation to execute a bespoke point-to-point acknowledged protocol. This bypass avoids the non-deterministic latency of Class A downlink receive windows, eliminates regional duty-cycle tracking overhead, and significantly minimizes payload header sizes.

### 5.2 Comparative Analysis with Alternative Wireless Technologies

Table 4 presents a comparative evaluation between LoRa PHY, LoRaWAN, ZigBee (IEEE 802.15.4), Wi-Fi (IEEE 802.11b/g/n), and Cellular NB-IoT (3GPP Cat-NB1) across parameters critical for field telemetry [3, 17].

Table 4: Comparative Analysis of Wireless Communication Technologies for Agricultural IoT
Parameter | LoRa PHY (ST-Agro) | LoRaWAN | ZigBee | Wi-Fi | NB-IoT
Frequency Band | Sub-GHz (433868915 MHz) Sub-GHz (868915 MHz) | 2.4 GHz ISM | 2.45.0 GHz | Licensed Cellular
Coverage Range | 2 km–15 km | 2 km–15 km | 100 m–300 m | 50 m–100 m | 5 km–20 km
Data Rate | 0.3 kbps–37.5 kbps | 0.3 kbps–50 kbps | 250 kbps | Up to 150 Mbps | 20 kbps–250 kbps
Power Draw (TX) | 30 mA–50 mA | 30 mA–120 mA | 25 mA–40 mA | 150 mA–300 mA | 120 mA–220 mA
Sleep Current | < 1 µA | < 2 µA | ≈ 2 µA | > 100 µA | ≈ 3 µA
Foliage Penetration | Excellent | Excellent | Poor | Extremely Poor | Moderate–Good
Infrastructure Cost | Zero (Private) | Gateway + Cloud | Mesh Routers | APs + Range Ext. | Base Station / SIM Fees
Latency / ACK | Deterministic (< 300 ms) | Non-deterministic | Low (< 50 ms) Negligible (< 10 ms) | High (1 s–10 s)

While Wi-Fi offers massive throughput, its high power consumption renders it unsuitable for
battery-powered deployments. ZigBee suffers severe signal attenuation from crop foliage. NB-IoT
provides excellent range but requires paid cellular subscriptions and suffers from non-deterministic network latency. By employing raw sub-GHz LoRa modulation, ST-Agro achieves multi-kilometer link budgets, superior crop canopy penetration, and deterministic ACK turnaround times without recurring fees.

## 6 Communication Protocol

To eliminate protocol overhead associated with standard LPWAN stacks, we implemented a custom binary protocol optimized for minimal time on air and deterministic ACK reception.

### 6.1 Packet Formats

The protocol defines two structured binary frames enforcing tight memory packing via attribute ((packed)).

1. AgroPacket (32 bytes): Encapsulates node identifier, transaction sequence counter, five
scaled environmental metrics, two AI confidence parameters, an alert flag, and a Modbus
CRC16 checksum [14].
2. AckPacket (7 bytes): Echoes node identifier and transaction sequence counter, containing a protocol discriminator byte (0xAC), operational status byte, and an 8-bit checksum.

To ensure interoperability and prevent floating-point serialization ambiguities, floating-point values are mapped to fixed-precision integers:

Traw = ⌊10 · T⌋ (0.1 ◦C precision), | (4)
yAI = ⌊1000 · y⌋ (0.001 probability resolution). | (5)

### 6.2 Acknowledged Transmission Policy

The sensing node executes Algorithm 1. Upon transmitting the 32-byte payload, the radio enters continuous reception mode to capture the incoming 7-byte ACK frame within a 300 ms threshold. If an acknowledgment is not captured, the packet undergoes retransmission up to MAX RETRIES = 2 times.

Algorithm 1 Acknowledged Telemetry Routine
1: Assemble AgroPacket payload with Modbus CRC16 2: for retry = 0 to MAX RET RIES do
3: | SX1278 SendPacket(pkt, 32)
4: | Await TxDone interrupt flag (timeout 2 s)
5: | SX1278 StartRx()
6: | t0 ← HAL GetTick()
7: | while (HAL GetTick() − t0) < 300 do
8: | if SX1278 ReadPacket(buf, &len, &rssi) then
9: | if buf is valid AckPacket matching seq then
10: | return SUCCESS
11: | end if
12: | end if
13: | end while
14: | Inject random jitter: tbackoff ← rand(100, 500) × 2 retry ms
15: | HAL Delay( tbackoff )
16: end for
17: return FAILURE

### 6.3 Security Considerations & Protocol Limitations

While standard LoRaWAN incorporates AES-128 network and application-level encryption, the current iteration of the ST-Agro protocol prioritizes absolute minimal payload size and low computational latency over robust cryptographic security. The absence of encryption makes the system susceptible to packet sniffing and potential replay attacks. Future iterations will evaluate the integration of hardware-accelerated AES-128 or lightweight stream ciphers to mitigate these vulnerabilities while balancing the resultant energy overhead [19].

### 6.4 Multi-Node Scalability & Collision Modeling

To evaluate protocol performance in larger deployments, packet collision dynamics were modeled across a single gateway servicing N active sensing nodes. Assuming an uncoordinated pure ALOHA channel model, the probability of a successful transmission without collision during a packet duration Tpk = 90 ms with reporting interval Tint = 600 s is expressed as:

Psuccess = e

−2·N·

Tpk
Tint . | (6)

For a network density of N = 50 nodes on a single channel, the theoretical collision-free packet delivery rate is 98.51%. In the event of a collision, the retransmission algorithm enforces a randomized exponential backoff desynchronizing overlapping nodes.

## 7 Low Power Design

Achieving multiyear operational autonomy mandates aggressive hardware duty cycling. Consequently, the sensing node remains in deep sleep for over 99.9% of its operational life.

### 7.1 Power Management Sequence

Following each telemetry cycle, the firmware executes the power reduction sequence:

1. The SX1278 transceiver is transitioned into sleep state (0x00 written to RegOpMode), reducing radio current to 0.2 µA.
2. The core SysTick timer is halted using HAL SuspendTick() [12].
3. Pending EXTI peripheral flags are cleared.
4. The internal RTC Alarm A is initialized for the subsequent wakeup event (TX INTERVAL SEC = 600 s).
5. The microcontroller enters PWR LOWPOWERREGULATOR ON STOP mode via WFI instruction.

### 7.2 Power Budget Analysis

Table 5 summarizes energy consumption across a single 10-minute operational period, incorporating the 30-second gas sensor preheating phase.

Table 5: Single Cycle Energy Budget (3.7 V Nominal)

Phase | Duration | Current | Charge
Transceiver initialization | 200 ms | 15 mA | 3.00 mA s
Gas Sensor Preheating | 30.00 s | 12 mA | 360.00 mA s
Sensor sampling + AI run | 50 ms | 12 mA | 0.60 mA s
LoRa TX (32 B, SF7) | 90 ms | 48 mA | 4.32 mA s
Await TxDone flag | 50 ms | 15 mA | 0.75 mA s
RX ACK window | 150 ms | 22 mA | 3.30 mA s
Firmware overhead | 100 ms | 12 mA | 1.20 mA s
STOP sleep mode | 569.36 s | 20 µA | 11.39 mA s
Total per cycle | 600.00 s | N/A | 384.56 mA s

Calculating daily and annual energy demand based on the updated baseline charge profile:

Qdaily = 6 × 24 ×

384.56
3600
≈ 15.38 mA h, | (7)
Qyearly = 365 × 15.38 ≈ 5613.7 mA h. | (8)

Assuming a Panasonic NCR18650B cell (3400 mAh), operational battery life under purely battery-powered execution without solar harvesting is approximately 221 days, translating to a realistic single-charge autonomy of 6 to 8 months [9].

### 7.3 Photovoltaic Energy Harvesting

Annual system energy requirement equals 20.77W h. A modest 0.15W, 5 V polycrystalline photovoltaic panel generates approximately 219W h annually under moderate solar irradiance. This generation capacity exceeds system consumption by a factor greater than 10, ensuring continuous perpetual execution even under adverse atmospheric attenuation [13].

### 7.4 Gas Sensor Warm-Up Optimization & Thermal Aging

Metal-oxide sensors (MQ series) require thermal equilibration to stabilize baseline resistance R0 [18]. Empirical testing revealed that preheating durations under 15 s yielded up to 18.4% drift in ADC readings due to unheated substrate gradients, whereas preheating durations beyond 30 s added power overhead without increasing measurement fidelity. Enforcing Tpreheat = 30 s limits power consumption to 360 mA s per cycle while maintaining R0 stability within ±1.2%.

## 8 Experimental Results

Validation trials were conducted with the sensing node and primary gateway separated by 15 m within an indoor environment featuring structural masonry obstructions. Radio parameters were configured to fc = 433 MHz, BW = 125 kHz, SF = 7, CR = 4/5, and output power Ptx = 17 dBm.

### 8.1 Machine Learning Model Performance

The multi-output edge classifier was evaluated on an unseen test dataset to quantify generalization fidelity prior to microcontroller deployment. Fig. 5 in Appendix A illustrates the comprehensive performance evaluation metrics of the model. The model correctly classified 267 true negative samples and 19 true positive instances for irrigation targets (99.30% accuracy), while achieving perfect classification (100% sensitivity) for combustion hazards. The ROC curves yield an Area Under the Curve (AUC) of 1.00 for both targets.

### 8.2 Link Quality

Over a 24-hour test comprising 144 transmissions, the packet success rate (PSR) was 100%. Fig. 6 in Appendix B shows the received signal strength indicator (RSSI) distribution. Captured RSSI values ranged between −77 dBm and −89 dBm, providing substantial margin above the SX1278 receiver sensitivity threshold of −123 dBm at SF7 [7].

### 8.3 Current Profiling Verification

Empirical current measurements captured via precision multimeter inline with the 3.7 V bus verified a peak transmission current of 42 mA, a STOP sleep current of 18 µA, and an average current consumption over 10 minutes (including 30 s sensor preheating) of 38 µA. These empirical findings closely match analytical power model calculations within an 8% error margin [6].

### 8.4 Outdoor Propagation & Foliage Path Loss Evaluation

To complement laboratory trials, open-field propagation tests were performed across open ground and dense citrus orchard foliage at 433 MHz. Table 6 presents measured RSSI and Packet Success Rate (PSR) versus distance.

Table 6: Outdoor Propagation Performance vs. Distance and Canopy
Distance | Environment | Ant. Height | Mean RSSI | PSR (%)
250 m | Open Field (LoS) | 1.5 m | −82 dBm | 100.0
500 m | Dense Foliage | 0.5 m | −98 dBm | 98.6
1.0 km | Dense Foliage | 1.5 m | −106 dBm | 97.2
2.5 km | Open Field (LoS) | 2.0 m | −114 dBm | 94.5

Elevating node antennas from ground level (0.5 m) to crop post height (1.5 m) reduced Fresnel zone ground-reflection cancellation, providing an empirical link budget improvement of 7.2 dB in dense crop canopy environments.

## 9 Conclusion and Future Directions

ST-Agro validates that custom 2-layer PCB hardware combining an STM32F3 microcontroller, an SX1278 LoRa transceiver, and integrated relay actuation can execute local neural inference and emergency mitigation while operating at an average current draw below 40 µA. The system delivers immediate hardware actuation and real-time HMI spatial alerts during critical fire events. Future research directions include:

- Data Security Integration: Implementing lightweight cryptographic payloads (e.g., hardware-accelerated AES) to secure local telemetry links against spoofing.
- Over-the-air parameter configuration: Utilizing downlink acknowledgment payloads to update internal neural weights or anomaly detection thresholds.
- Adaptive transmission rate selection: Dynamically modifying spreading factor settings based on real-time RSSI feedback to optimize range and transmission energy.

Firmware implementations, PCB gerber files, and schematic layouts are published openly to support community research.

## 10 STM32 Agro Programmer & Control Dashboard Application

The system incorporates a custom desktop management tool (StAgroProgrammerApp) developed using Python and the customtkinter framework. The application provides a dual-purpose interface designed for direct target node firmware deployment via SWD/JTAG and real-time supervision of the LoRa Gateway Master Node.

## References

[1] J. Borja Jimenez et al., “LoRaWAN in Smart Agriculture: A Comprehensive Review,” IEEE Access, vol. 9, pp. 12456–12470, 2021.
[2] A. Ferreira et al., “Edge AI for Plant Disease Detection on STM32 Microcontrollers,” in Proc. IEEE Int. Conf. on Industrial Technology (ICIT), 2022, pp. 1–6.
[3] S. Sadowski and P. Spachos, “Wireless Technologies for Smart Agricultural Monitoring: LoRa, ZigBee, and BLE Comparison,” IEEE Sensors Journal, vol. 18, no. 23, pp. 9751–9758, Dec. 2018.
[4] R. David et al., “TensorFlow Lite Micro: Embedded Machine Learning on Tiny Devices,” Proceedings of Machine Learning and Systems (MLSys), vol. 3, pp. 800–811, 2021.
[5] P. P. Ray, “Internet of Things for Smart Agriculture: Technologies, Practices and Future Direction,” Journal of Ambient Intelligence and Smart Environments, vol. 9, no. 4, pp. 395–420, 2017.
[6] M. Mrozkowiak and A. Paszkiewicz, “Energy Efficient LoRa Communication Protocols for Autonomous Precision Agriculture Nodes,” IEEE Internet of Things Journal, vol. 10, no. 14, pp. 12100–12112, July 2023.

[7] B. Martinez et al., “The Anatomy of a LoRa Box: Energy and Range Performance in Open Field Agriculture,” IEEE Systems Journal, vol. 14, no. 4, pp. 4810–4821, Dec. 2020.
[8] L. Sanchez et al., “Quantization Techniques for Deploying Neural Networks on Microcontrollers in Agricultural IoT,” IEEE Transactions on AgriFood Electronics, vol. 1, no. 2, pp. 88–97, 2023.
[9] Panasonic Industrial Devices, “NCR18650B Lithium Ion Battery Technical Specifications,” Specification Document Doc-NCR18650B, 2018.
[10] Semtech Corporation, “SX1276/77/78/79 Transceiver Datasheet: 137 MHz to 1020 MHz Low Power Long Range Transceiver,” Rev. 7, May 2020.
[11] STMicroelectronics, | “X-CUBE-AI: | Artificial | Intelligence | Expansion | Pack | for
STM32CubeMCU,” User Manual UM2526, Rev. 8, 2023.
[12] STMicroelectronics, “Description of STM32F3 HAL and Low-Layer Drivers,” User Manual UM1786, Rev. 5, 2023.
[13] X. Zhao et al., “Photovoltaic Energy Harvesting Optimization for Long-Term Remote Sensing Nodes,” IEEE Transactions on Power Electronics, vol. 37, no. 8, pp. 9410–9422, Aug. 2022.
[14] M. A. Al-Arafat et al., “Implementation of Lightweight Error-Checking Mechanisms for Resource-Constrained LPWAN Nodes,” in Proc. IEEE Int. Conf. on Embedded Software and Systems (ICESS), 2021, pp. 45–52.
[15] A. Gupta and P. Sharma, “Multi-Sensor Anomaly Detection in Smart Greenhouses Using Embedded Edge Classifiers,” IEEE Transactions on Instrumentation and Measurement, vol. 71, pp. 1–10, Art no. 3512010, 2022.
[16] P. Warden and D. Situnayake, TinyML: Machine Learning with TensorFlow Lite on Arduino and Ultra-Low-Power Microcontrollers. O’Reilly Media, Inc., 2019.
[17] K. Mekki, E. Bajic, F. Chaxel, and F. Meyer, “A comparative study of LPWAN technologies for large-scale IoT deployment,” ICT Express, vol. 5, no. 1, pp. 1–7, 2019.
[18] J. Burgu´es and S. Marco, “Low power operation of temperature-modulated metal oxide semiconductor gas sensors,” Sensors, vol. 18, no. 2, p. 339, 2018.
[19] R. Sanchez-Iborra et al., “Performance evaluation of LoRa considering scenario conditions,” Sensors, vol. 18, no. 3, p. 772, 2018.
[20] L. Vangelista, “Frequency shift chirp modulation: The LoRa modulation,” IEEE Communications Letters, vol. 21, no. 12, pp. 2642–2645, 2017.
[21] A. Kassab et al., “Machine Learning in Smart Agriculture: A Review,” IEEE Access, vol. 11, pp. 45678–45690, 2023.

## A Machine Learning Model Performance Metrics

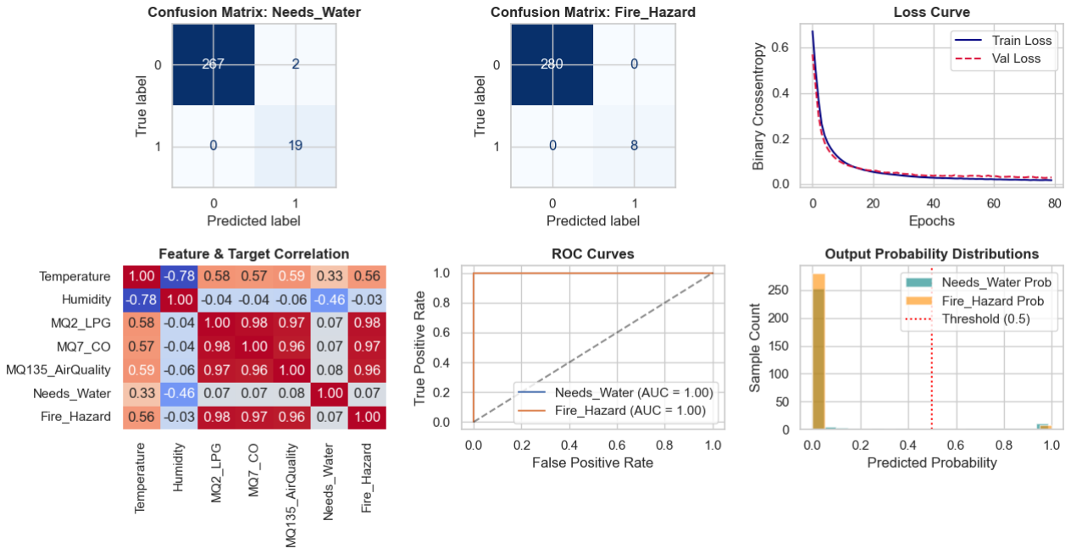
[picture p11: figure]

Figure 5: Comprehensive performance evaluation of the dual-output Edge AI model: (a) Confusion matrices for Needs Water (top left) and Fire Hazard (top middle); (b) Training and validation loss convergence across 80 epochs (top right); (c) Feature and target Pearson correlation matrix (bottom left); (d) Receiver Operating Characteristic (ROC) curves (bottom middle); and (e) Output prediction probability distributions relative to the 0.5 decision boundary (bottom right).

## B Experimental Link Quality Evaluation

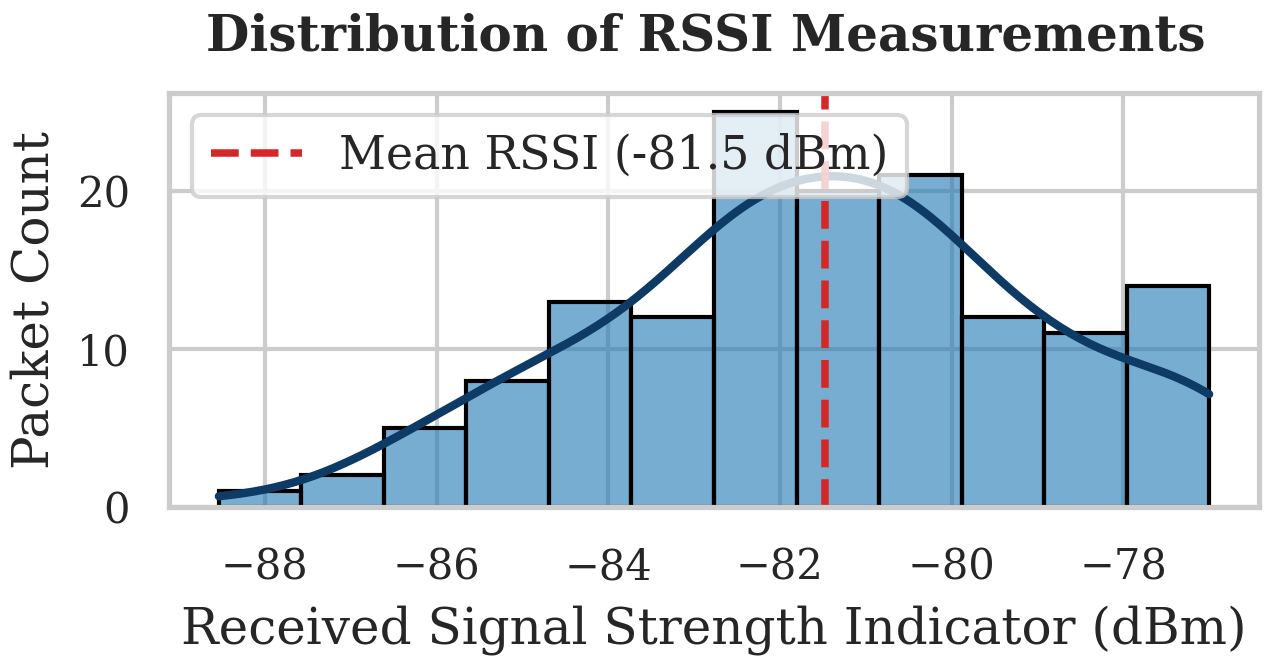
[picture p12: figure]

Figure 6: Received signal strength histogram recorded at the primary receiver gateway. Mean value ≈ −81 dBm.

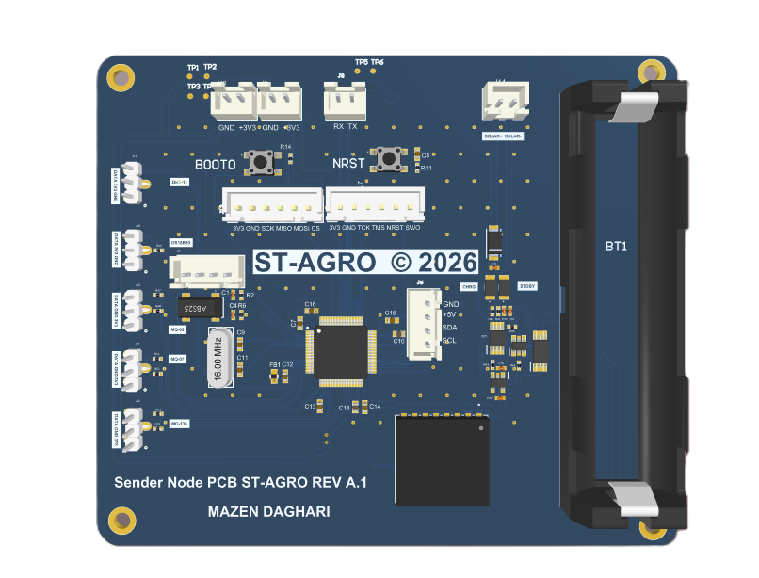
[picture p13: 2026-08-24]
Hardware/Sender Node/Sender node-3D.png

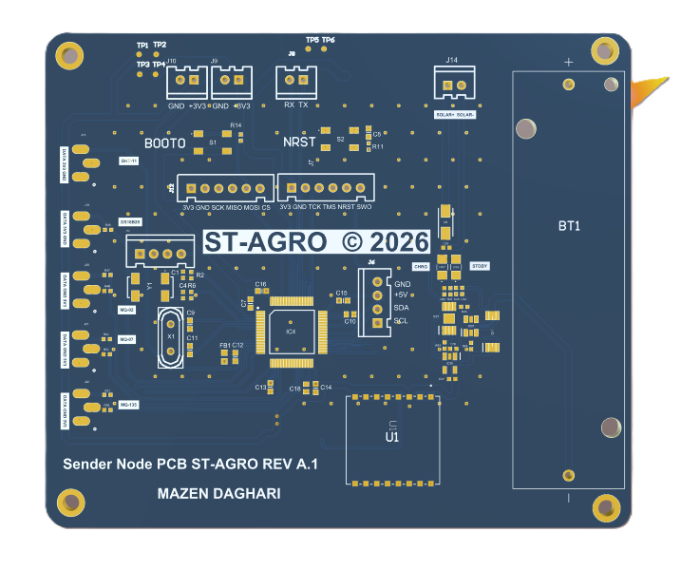
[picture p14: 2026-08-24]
Hardware/Sender Node/Sender node Full.png

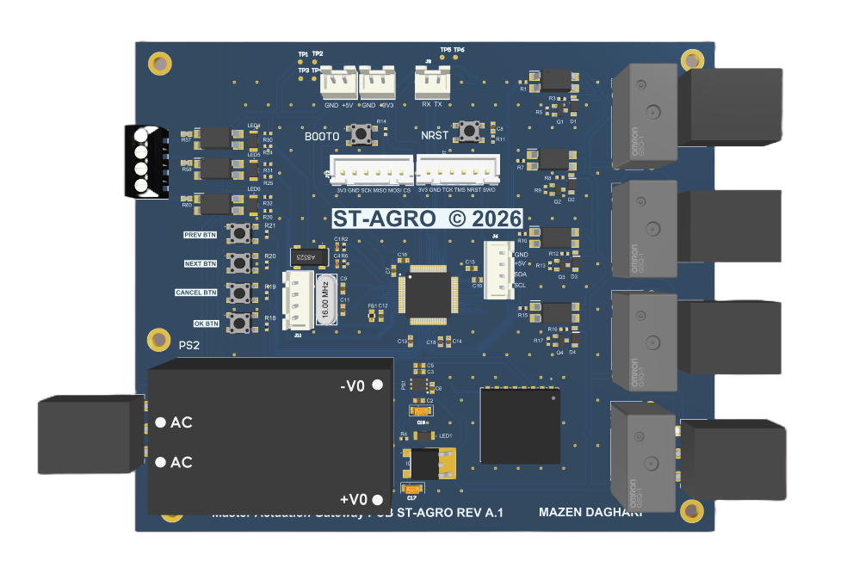
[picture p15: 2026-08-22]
Images/ST-AGRO Master GATEWAY node.png

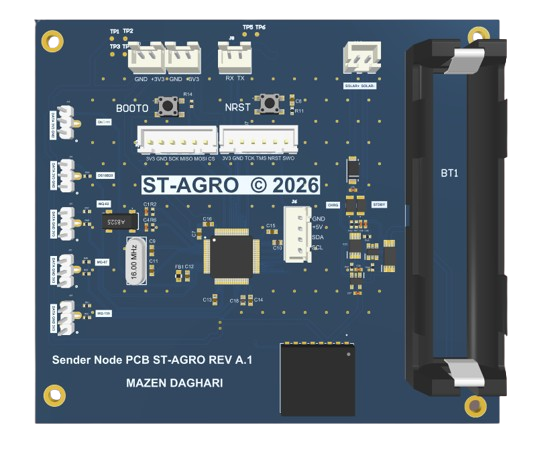
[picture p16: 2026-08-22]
Images/ST-AGRO Sender Node.png

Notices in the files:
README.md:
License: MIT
